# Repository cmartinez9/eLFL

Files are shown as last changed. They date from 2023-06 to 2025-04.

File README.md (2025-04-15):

# eLFL (Electric Little Free Library)

## Description

An electric Little Free Library (eLFL) is a regular Little Free Library retrofitted with a solar PV panel, battery storage, and charging electronics. It is developed by students at UW-Madison in collaboration with the Great Lakes Community Conservation Corps (GLCCC). It serves as a way to provide free community access to clean electricity. 

## Requirements

- Altium Designer 
- Arduino IDE [Used 2.0.4]
- Python

## Installation

* **eLFL Node** 
    
    * Arduino IDE
        * Open eLFL_Node_v1.ino
        * Download [RadioHead.h](http://www.airspayce.com/mikem/arduino/RadioHead/RadioHead-1.122.zip)
        * Go to "Sketch" -> "Include Library" -> "Add .ZIP Library" -> Select downloaded RadioHead library

## Bill of Materials

|Quantity|Part Number|Desription|Supplier Link|Unit Price|Group|
|:----|:----|:----|:----|:----|:----|
|3|ABX00033|ARDUINO NANO EVERY WITH HEADERS| |16|eLFL PCB|
|6|SEN-13679|CURRENT SENSOR BREAKOUT - ACS723| |9.95|eLFL PCB|
|6|PPTC151LFBN-RC|CONN HDR 15POS 0.1 TIN PCB| |0.98|eLFL PCB|
|3|PPTC051LFBN-RC|CONN HDR 5POS 0.1 TIN PCB| |0.47|eLFL PCB|
|6|SR205E105MAR|CAP CER 1UF 50V Z5U RADIAL| |0.85|eLFL PCB|
|3|PPTC061LFBN-RC|CONN HDR 6POS 0.1 TIN PCB| |0.52|eLFL PCB|
|3|TMP36GT9Z|SENSOR ANALOG -40C-125C TO92-3| |2.4|eLFL PCB|
|3|PPPC091LFBN-RC|CONN HDR 9POS 0.1 GOLD PCB| |0.67|eLFL PCB|
|3|SSL-LX5093LGD|LED GREEN DIFFUSED T-1 3/4 T/H| |0.43|eLFL PCB|
|9|3568|FUSE HOLDER BLADE 500V 30A PCB| |1.33|eLFL PCB|
|3|HLMP-3301|LED RED DIFFUSED T-1 3/4 T/H| |0.47|eLFL PCB|
|6|106CKS450MLU|CAP ALUM 10UF 20% 450V RADIAL| |0.97|eLFL PCB|
|18|1729128|TERM BLK 2P SIDE ENT 5.08MM PCB| |1.162|eLFL PCB|
|3|DEV-13955|OPENLOG WITH HEADERS| |17.5|eLFL PCB|
|3|VOLT-01|VOLTAGE SENSOR MODULE| |5.95|eLFL PCB|
|3|S152AH-915S|RF ANT 915MHZ WHIP TILT RP-SMA| |15.41|eLFL PCB|
|9|PPPC031LFBN-RC|CONN HDR 3POS 0.1 GOLD PCB| |0.37|eLFL PCB|

## Usage

Use a 12V battery, Solar Charge Controller, Solar Panel, and Printed Circuit Board.

## Contributing

[Insert instructions for how others can contribute to your project. This could include guidelines for submitting bug reports, suggestions for new features, or instructions for how to contribute code.]

## Credits

[Insert credits for any third-party libraries, resources, or tools that you used in your project.]

## License

[Insert the license that your project is released under. This could be a standard open-source license like the MIT License or a custom license that you created specifically for your project.]

## Contact

Christian Martinez (cmartinez9@wisc.edu)

Maitreyee Marathe (mmarathe@wisc.edu)

Mridhul Baskaran (mbaskaran@wisc.edu)

Joshika Nachiappan (nachiappanra@wisc.edu)

Savannah Ahnen (sahnen@wisc.edu)

Giri Venkataramanan (giri@engr.wisc.edu)

Bhuvana Krishnaswamy (bhuvana@ece.wisc.edu)

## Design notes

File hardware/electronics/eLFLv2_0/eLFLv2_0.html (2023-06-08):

Reporting Options

# File in Newer Format

Date | : | 4/23/2022
Time | : | 3:18:30 PM
Project name | : | C:\Users\Public\Documents\Altium\Projects\elfl\eLFLv2_0\eLFLv2_0.PrjPcb
Schematic documents | : | eLFLv2_0.SchDoc

Version | Warning
21.9.0 | Internal Pull Up/Down resistor in components are not supported in this version.

These files were generated in a later version of Altium Designer. Be aware that some data may have been added through functionality not available in your current version and will therefore not be available to you.

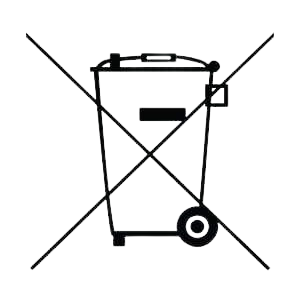
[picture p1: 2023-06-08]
hardware/electronics/eLFL_Particle_Breakout/noTrash-removebg-preview.png

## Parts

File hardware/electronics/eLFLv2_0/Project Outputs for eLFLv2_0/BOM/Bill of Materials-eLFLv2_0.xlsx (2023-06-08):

Comment | Description | Designator | Footprint | LibRef | Quantity
Terminal Connector | Barrier Strip Terminal Block, 13.5A, 1.5mm2, 1 Row(s), 1 Deck(s) | 12V Battery, Door Sensor, Output of Batt Charger, USB1, USB2 | Anderson Power Pole | 1729128 | 5
3568 | Fuses/Accessories | Battery Fuse, USB1 Fuse, USB2 Fuse | Fuse | 3568 | 3
Buck Converter | Buck Converter 5V output | BC1 | Buck Converter | Buck Converter | 1
10uF | Aluminum Electrolytic Capacitor, Polarized, Aluminum (wet), 450V, 20% +Tol, 20% -Tol, 10uF, Through Hole Mount | C1 | Capacitor | 106CKS450MLU | 1
1uF | Capacitor | C2 | RAD-0.3 | Cap | 1
10uF | Ceramic Capacitor, Multilayer, Ceramic, 100V, 10% +Tol, 10% -Tol, X6S, 22% TC, 10uF, Surface Mount, 1206 | C3, C4 | Ceramic Capacitor | C3216X6S2A106K160AC | 2
HLMP-3301 | T-1 3/4 (5 mm) Diffused LED Lamp, 1.9 V, -40 to 100 degC, 2-Pin THD, RoHS, Bulk | Green, Red | AVAG-HLMP-3301-2 | CMP-2000-06411-1 | 2
12uF | General Purpose Inductor, 12uH, 20%, 1 Element, SMD, 1813 | I1 | Inductor | RLS-126-R Inductor | 1
ACS723 | Header, 5-pin | P1, P3 | Current Sensor | Current Sense | 2
OpenLog | Header, 6-Pin | P2 | HDR1X6 | Header 6 | 1
Real Time Clock | Real Time Clock, Volatile, 1 Timer(s), CMOS, PDIP8 | P5 | Real Time Clock | DS1307 | 1
Voltage Sensor | Header, 5-pin | Q | Voltage Sensor | Voltage Sense | 1
Res1 | Resistor | R1, R2, R3, R4 | AXIAL-0.3 | Res1 | 4
Mounting Hole | M2 PTH (2.5mm), 5mm pad | ST1, ST2, ST3, ST4 | PTH-M2D5X5 | CMP-00028-00004-2 | 4
Terminal Connector | Barrier Strip Terminal Block, 13.5A, 1.5mm2, 1 Row(s), 1 Deck(s) | T1, T2, T3, T4, T5 | Terminal Block | 1729128 | 5
TMP36GT9Z | Low Voltage Temperature Sensor, 2.7 to 5.5 V Supply, Industrial, 3-pin TO92 (T-3), Tray | U1 | HDR1X3 | ADI-TMP3X-T-3 | 1
ABX00053 | ARDUINO NANO RP2040 CONNECT WITH | U2 | Arduino Nano Every | ABX00053 | 1
RF95 Module |  | U3 | RF95 | RF95 Module | 1
Lora_Testpoints | This act as testing point for 9 pin header on Lora for ELFL projects | U4 | LORA TESTPOINTS | Lora_Testpoints | 1

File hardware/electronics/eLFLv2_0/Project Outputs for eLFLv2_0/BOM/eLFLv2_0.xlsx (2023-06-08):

Line # | Name | Description | Designator | Revision ID | Revision State | Revision Status | Quantity | Manufacturer 1 | Manufacturer Part Number 1 | Manufacturer Lifecycle 1 | Supplier 1 | Supplier Part Number 1 | Supplier Unit Price 1 | Supplier Subtotal 1
 | Terminal Connector | Barrier Strip Terminal Block, 13.5A, 1.5mm2, 1 Row(s), 1 Deck(s) | 12 V Battery Input, Battery Charge Control Output1, Door Sensor1, Load Output1, USB1, USB2 |  | Not managed |  | 6 | Phoenix Contact | 1729128 | Volume Production | Digi-Key | 277-1247-ND | 1.32 | 7.92
 | Voltage Sensor | Header, 5-pin | 12Voltage Sensor |  | Not managed |  | 1
 | ACS723 | Header, 5-pin | Battery Current Sensor1, Load Current Sensor1 |  | Not managed |  | 2
 | 1uF | Capacitor | C1, C5 |  | Not managed |  | 2
 | 10uF | Aluminum Electrolytic Capacitor, Polarized, Aluminum (wet), 450V, 20% +Tol, 20% -Tol, 10uF, Through Hole Mount | C4, C6 |  | Not managed |  | 2 | CDE Illinois Capacitor | 106CKS450MLU | Volume Production | Digi-Key | 106CKS450MLU-ND
 | 3568 | Fuses/Accessories | F1, F2, F3 |  | Not managed |  | 3 | Keystone Electronics | 3568 | Volume Production | Digi-Key | 36-3568-ND | 1.33 | 3.99
 | HLMP-3301 | T-1 3/4 (5 mm) Diffused LED Lamp, 1.9 V, -40 to 100 degC, 2-Pin THD, RoHS, Bulk | Green1, Red1 | CMP-2000-06411-1 | Released | Up to date | 2 | Broadcom Avago | HLMP-3301 | Volume Production | Newark | 40K0048 | 0.46 | 0.92
 | RF95 Module |  | Lora Module1 |  | Not managed |  | 1
 | Lora_Testpoints | This act as testing point for 9 pin header on Lora for ELFL projects | Lora Test Points1 |  | Not managed |  | 1
 | Open Log |  | OpenLog |  | Not managed |  | 1
 | Res1 | Resistor | R1, R2, R3, R4 |  | Not managed |  | 4
 | RTC Breakout Board |  | RTC |  | Not managed |  | 1
 | Mounting Hole | M2 PTH (2.5mm), 5mm pad | ST1, ST2, ST3, ST4 |  | Unknown server |  | 4
 | TMP36GT9Z | Low Voltage Temperature Sensor, 2.7 to 5.5 V Supply, Industrial, 3-pin TO92 (T-3), Tray | Temperature Sensor1 |  | Not managed |  | 1
 | ABX00053 | ARDUINO NANO RP2040 CONNECT WITH | U1 |  | Not managed |  | 1

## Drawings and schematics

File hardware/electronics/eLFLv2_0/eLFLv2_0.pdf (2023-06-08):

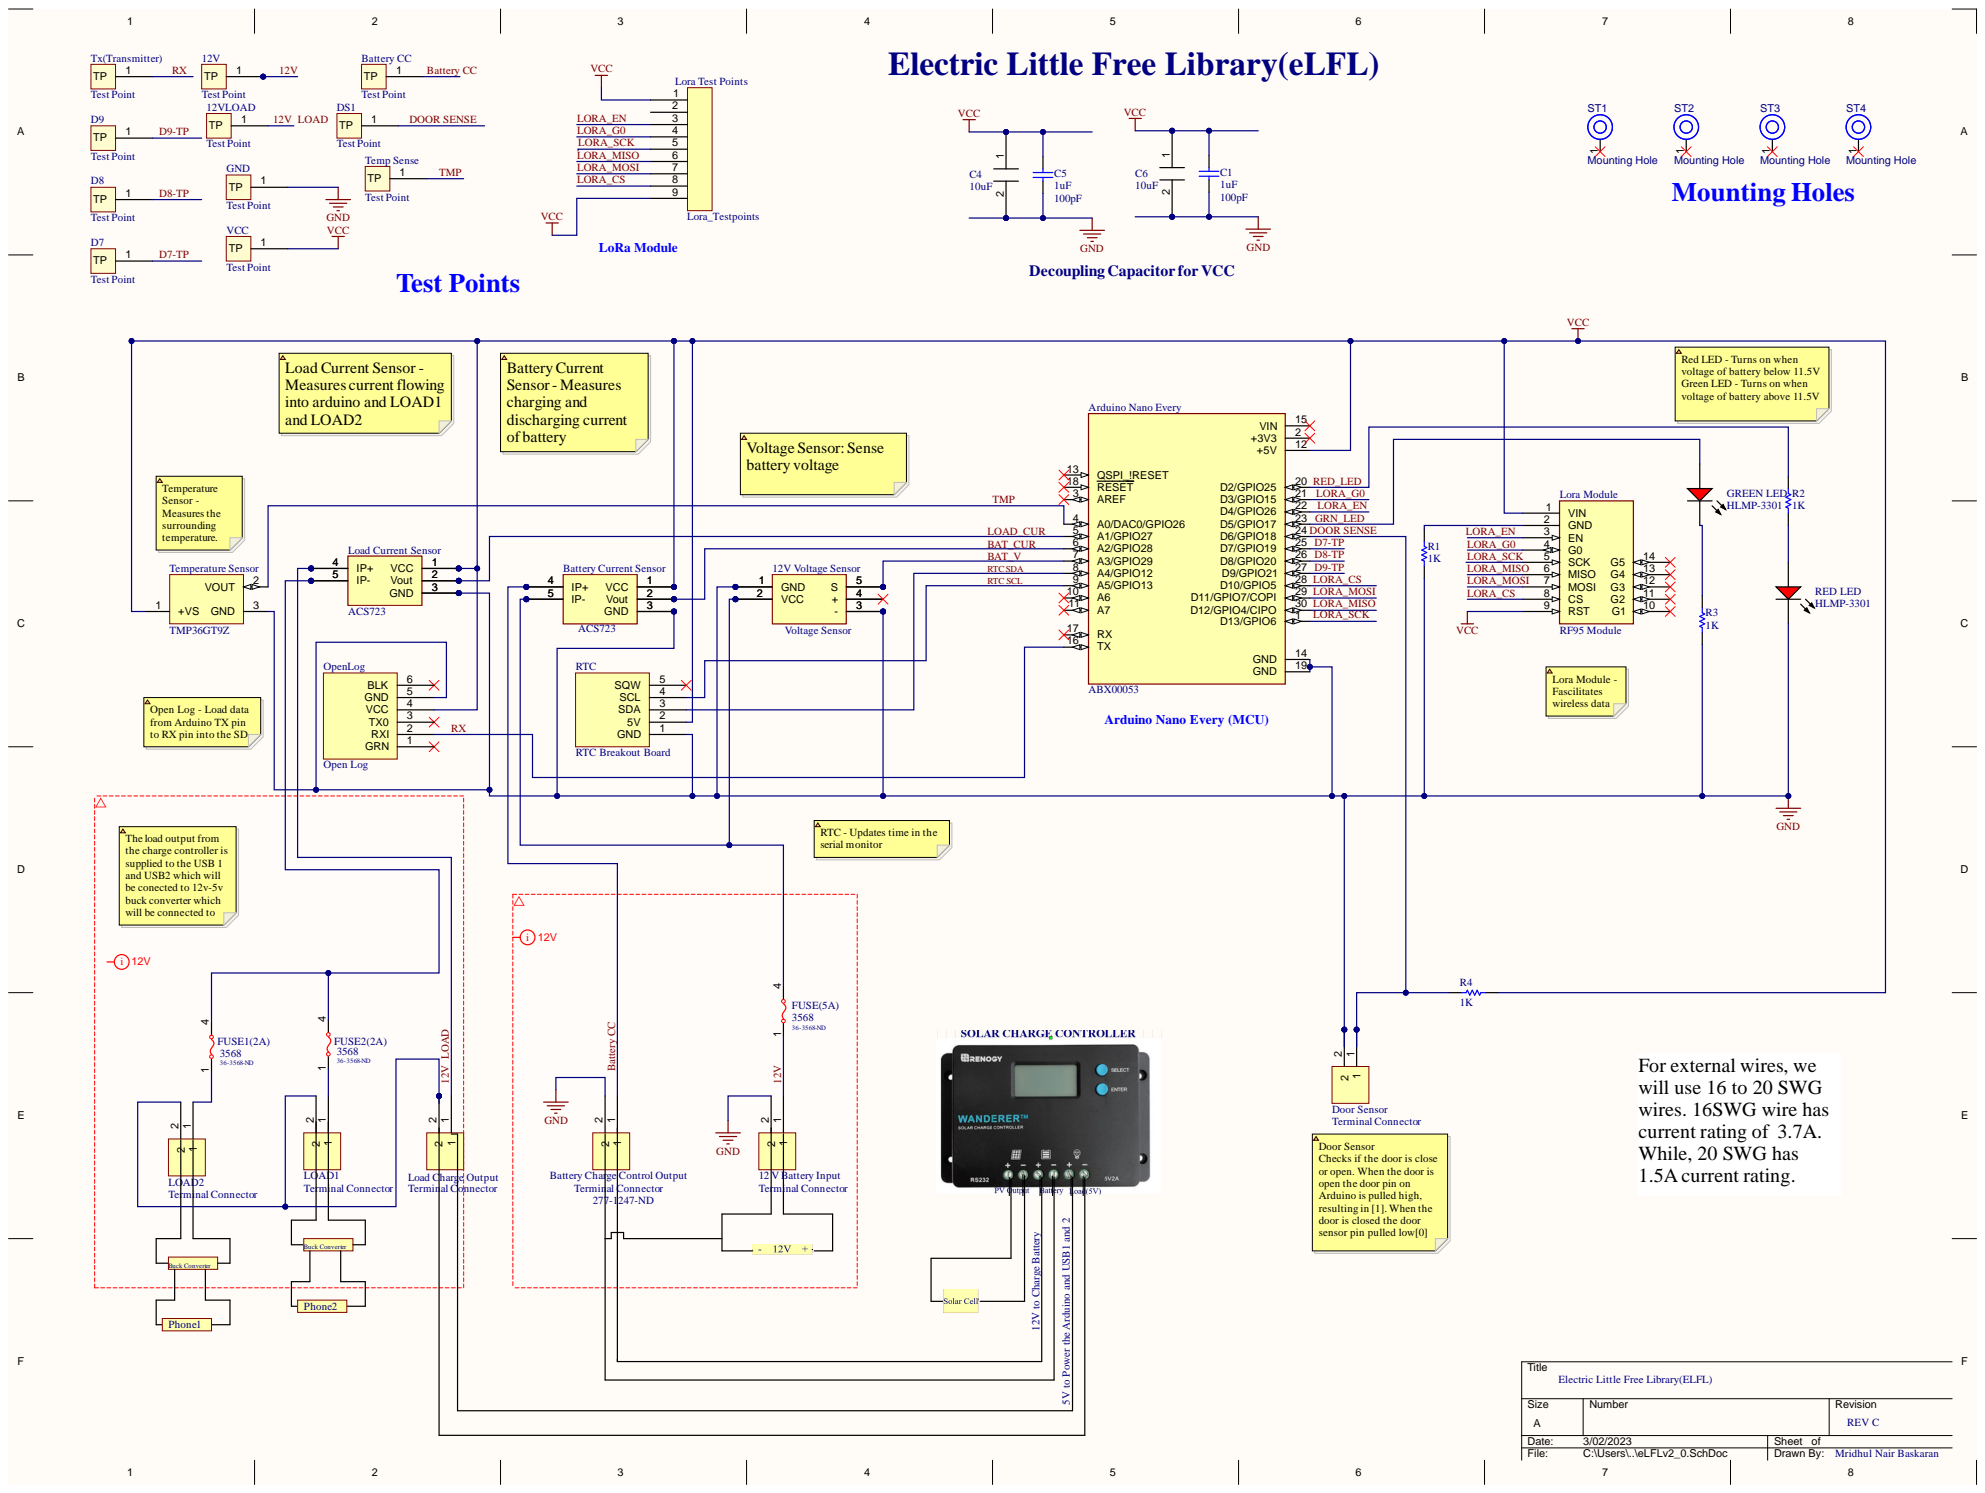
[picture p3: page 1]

Electric Little Free Library(eLFL)

Decoupling Capacitor for VCC

Red LED - Turns on when
voltage of battery below 11.5V
Green LED - Turns on when
voltage of battery above 11.5V

A1/GPIO27 5 | DOOR SENSE | LORA_EN | EN 3

OpenLog

Open Log - Load data
from Arduino TX pin
to RX pin into the SD

Arduino Nano Every (MCU)

RTC - Updates time in the
serial monitor

The load output from
the charge controller is
supplied to the USB 1
and USB2 which will
be conected to 12v-5v
buck converter which
will be connected to

For external wires, we
will use 16 to 20 SWG
wires. 16SWG wire has
current rating of 3.7A.
While, 20 SWG has
1.5A current rating.

Door Sensor
Checks if the door is close
or open. When the door is
open the door pin on
Arduino is pulled high,
resulting in [1]. When the
door is closed the door
sensor pin pulled low[0]

Load Charge Output Terminal Connector

Battery Charge Control Output
Terminal Connector

5V to Power the Arduino and USB1 and 2

Electric Little Free Library(ELFL)

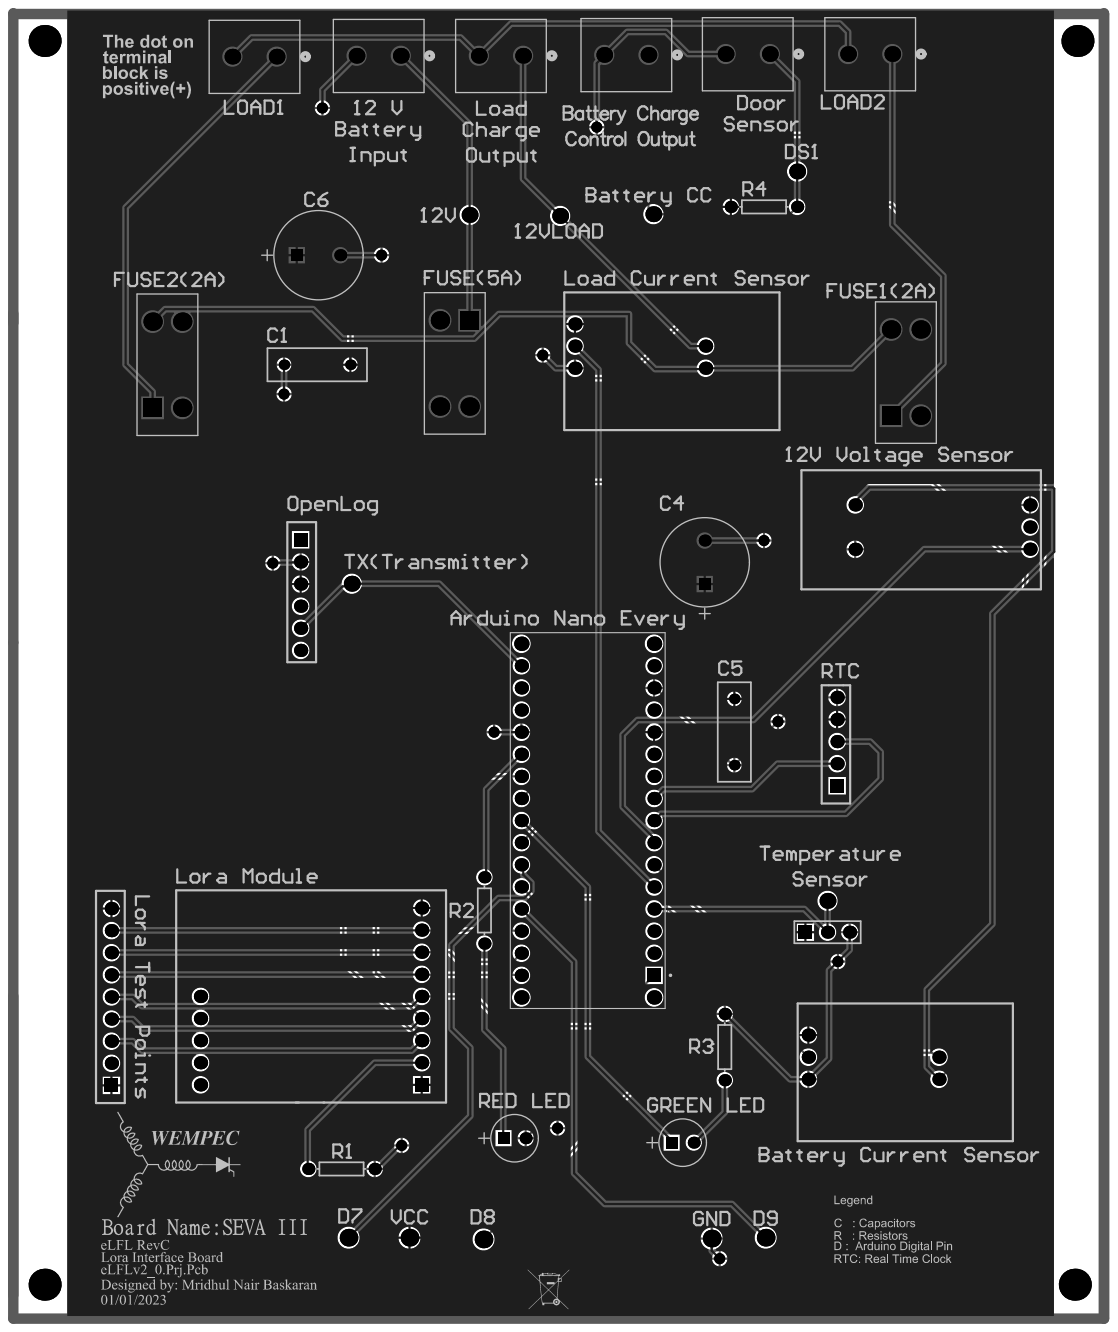
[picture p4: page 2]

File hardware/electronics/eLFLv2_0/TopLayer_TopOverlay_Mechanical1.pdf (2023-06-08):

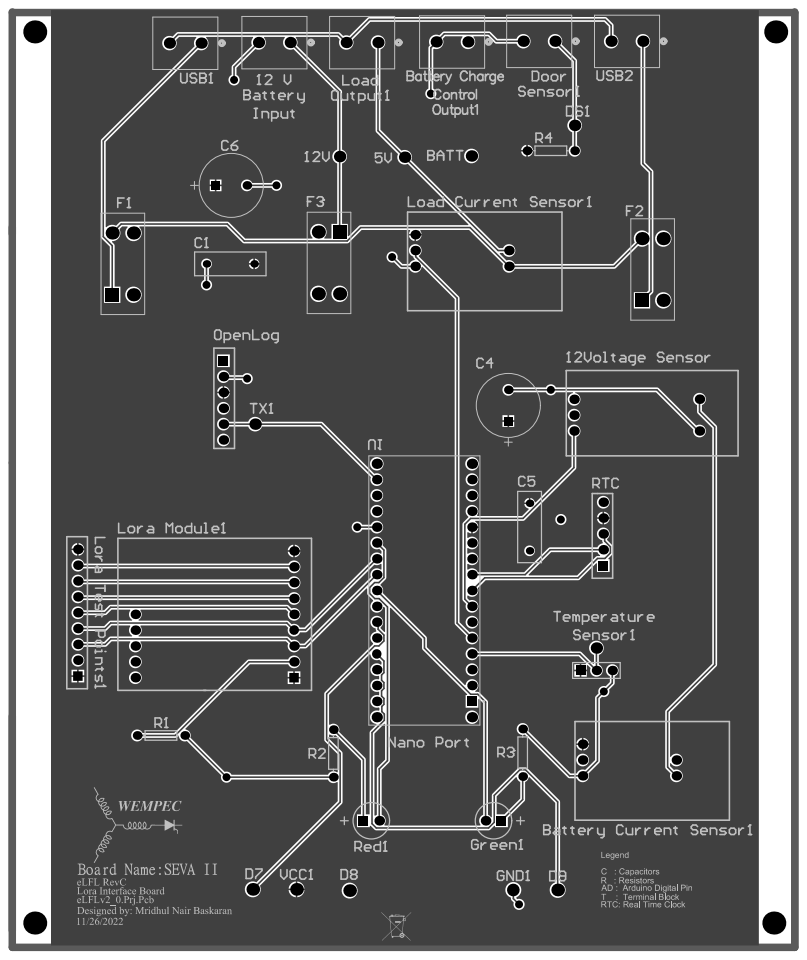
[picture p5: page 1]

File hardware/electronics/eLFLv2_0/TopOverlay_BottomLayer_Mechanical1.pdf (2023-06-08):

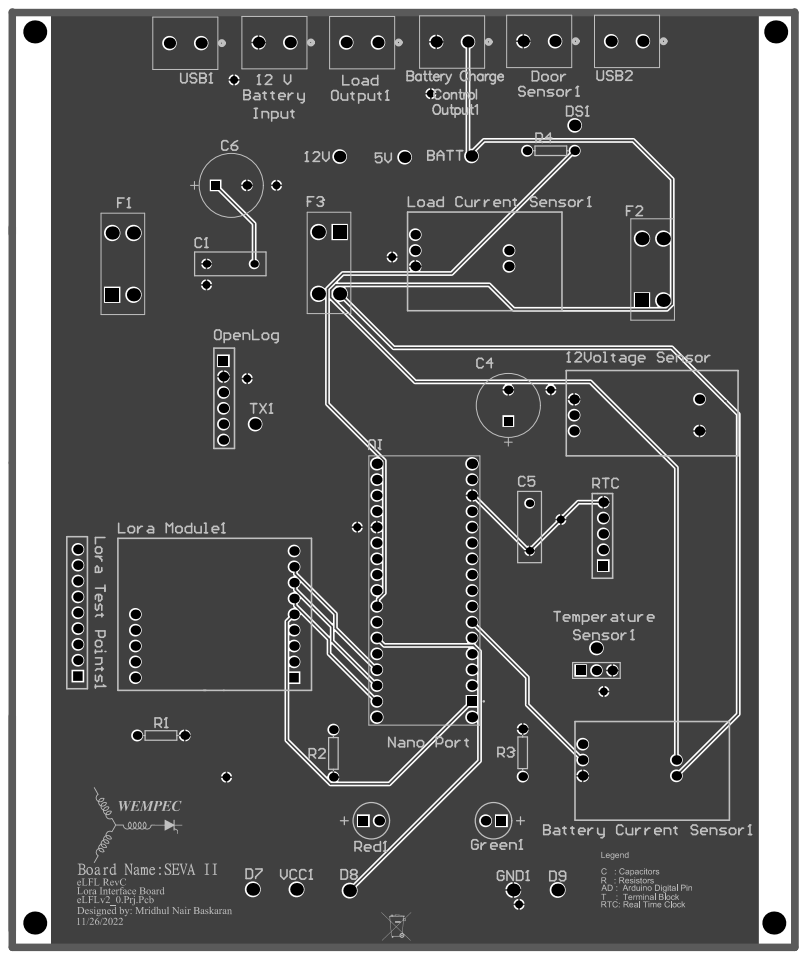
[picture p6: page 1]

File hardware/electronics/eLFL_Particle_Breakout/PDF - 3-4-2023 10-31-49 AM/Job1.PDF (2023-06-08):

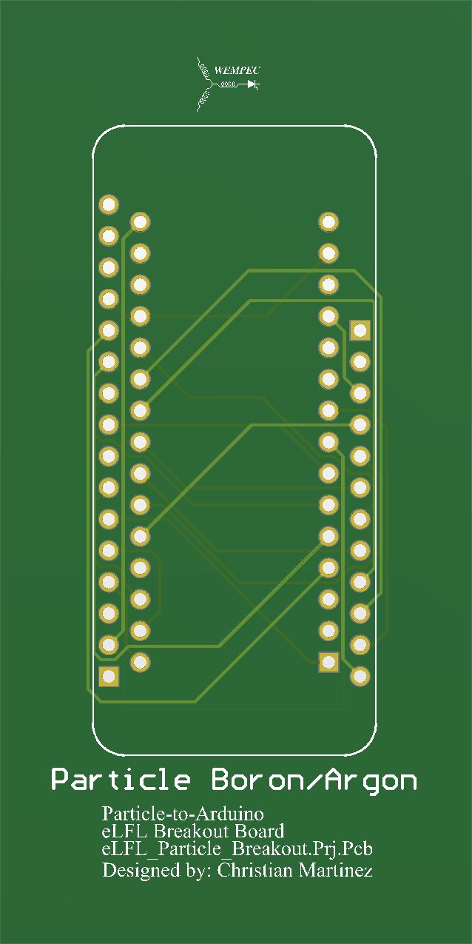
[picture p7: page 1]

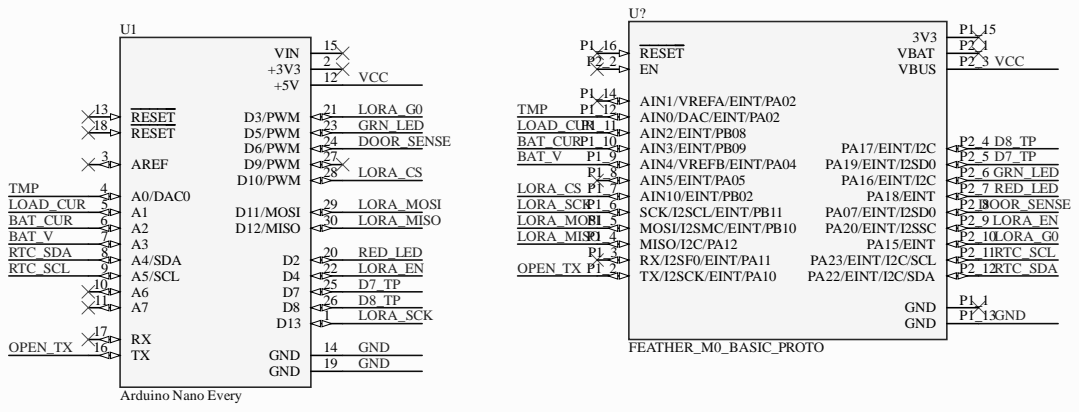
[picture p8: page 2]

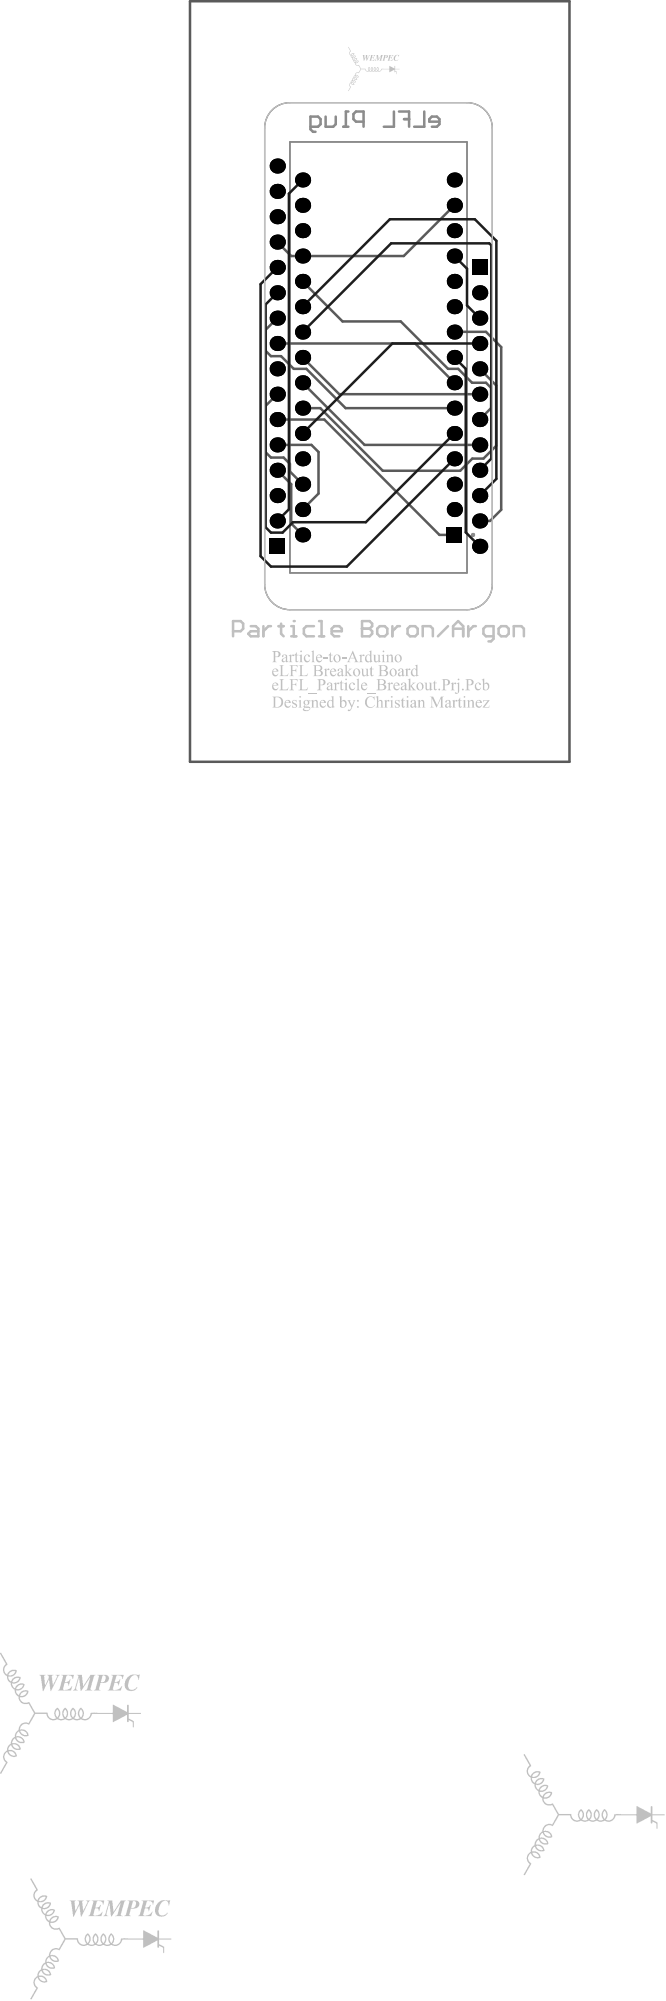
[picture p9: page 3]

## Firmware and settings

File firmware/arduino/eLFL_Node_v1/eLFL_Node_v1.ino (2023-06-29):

#include <ArduinoJson.h>
#include <ArduinoJson.hpp>


/* electric Little Free Library - v0
  Author: Maitreyee Marathe
  Last modified: Apr 1, 2022
  Platform: Arduino Nano Every
  This program is used to record sensor readings from a monitoring system for 
  a solar+battery powered USB charging station and log it to an SD card (OpenLog)
  connected via the TX pin.
  The Arduino Nano Every has two serial ports:
  "Serial" - for computer via micro-USB port
  "Serial1" - for the TX/RX pins (pins 16/17)

  Sensor Inputs
  - Load Current
  - Battery Current (+ve when getting charged)
  - Temperature
  - Battery Voltage

  Outputs
  - Green LED ON, Red LED OFF- voltage above v_high
  - Green LED OFF, Red LED ON - voltage below v_low
  - Previous state - voltage between v_low and v_high (deadband)
*/

// Date and time functions using a DS1307 RTC connected via I2C and Wire lib
//#include <LowPower.h>
//#include <RadioHead.h>
//#include <RH_RF95.h>
#include "RTClib.h"
// #include <ArduinoJson.h>
// #include <ArduinoJson.hpp>

RTC_DS1307 rtc;

#define NODE_ID 23

#define TEMP_SENSE
#define LOAD_SENSE
#define CUR_SENSE
#define V_SENSE
//#define DOOR_SENSE
//#define LORA_ACTIVE
//#define OPEN_LOG_ACTIVE
#define RTC_ACTIVE

#define MODEM_CONFIG 21

// +2 to +20, 13 default
// #define TX_POWER 23
// #define SF       10
// #define BW       125000
// #define CR       7
#define TX_POWER 23
#define SF 11
#define BW 500000
#define CR 5
#define EN 4

#ifdef LORA_ACTIVE
RH_RF95 rf95(10, 3);
#endif

#define TEMP_PIN A0
#define LOAD_PIN A1
#define CUR_BATT_PIN A2
#define V_BATT_PIN A3
#define DOOR_PIN A6
#define RED_LED_PIN 2
#define GRN_LED_PIN 5

// Sensor parameters
int iLoad_value = 0;
int iBatt_value = 0;
int temperature_value = 0;
int vBatt_value = 0;
int door_value = 0;
// delay time for every 10 minutes
unsigned long minute = 10;
unsigned long readDelay = minute * 60000;

float vBatt = 0;
const float sensitivity = 2.5;  // current sensor sensitivity
const float Vref_Load = 2500;   // load current sensor output voltage with no current
const float Vref_Batt = 2420;   // battery current sensor output voltage with no current
const float v_low = 11.5;       // battery voltage limit to switch ON red LED
const float v_high = 12;        // battery voltage limit to swithc ON green LED
const float logTime = 10000;    // time duration (ms) between two data entries to the SD card
const int delayTime = 2;        // time duration (ms) between two sensor readings
const int avgSamples = 10;      // no. of sensor readings to compute average

StaticJsonDocument<200> doc;

DateTime now;

void setup() {

  Serial.begin(9600);
  Serial.println("Start Init");
  initSensors();
#ifdef LORA_ACTIVE
  initLoRa();
#endif
  Serial.println("Finished Init");
}


void loop() {
  doc["node"] = NODE_ID;

#ifdef RTC_ACTIVE
  checkTime();
#endif

  sampleAnalog();

  calcValues();

#ifdef DOOR_SENSE
  checkDoor();
#endif

  chngLedStatus();

  // delay(logTime - delayTime*avgSamples);

  serializeJsonPretty(doc, Serial);
  Serial.println();
#ifdef LORA_ACTIVE
  sendPacket();
#endif
  doc.clear();
  delay(readDelay);
  // delay(logTime - delayTime*avgSamples);
  //LowPower.powerDown(SLEEP_8S, ADC_OFF, BOD_OFF);
}

bool initSensors() {
#ifdef TEMP_SENSE
  pinMode(TEMP_PIN, INPUT);
#endif
#ifdef LOAD_SENSE
  pinMode(LOAD_PIN, INPUT);
#endif
#ifdef CUR_SENSE
  pinMode(CUR_BATT_PIN, INPUT);
#endif
#ifdef V_SENSE
  pinMode(V_BATT_PIN, INPUT);
#endif
#ifdef DOOR_SENSE
  pinMode(DOOR_PIN, INPUT);
#endif
  pinMode(RED_LED_PIN, OUTPUT);
  pinMode(GRN_LED_PIN, OUTPUT);

#ifdef RTC_ACTIVE
  if (!rtc.begin()) {
    Serial.println("Couldn't find RTC");
    Serial.flush();
    while (1) delay(10);
  }


  if (!rtc.isrunning()) {
    Serial.println("RTC is NOT running, let's set the time!");
    // When time needs to be set on a new device, or after a power loss, the
    // following line sets the RTC to the date & time this sketch was compiled
    rtc.adjust(DateTime(F(__DATE__), F(__TIME__)));
  }
 
#endif
}

void checkTime() {
  now = rtc.now();
  String month = String(now.month(), DEC);
  String day = String(now.day(), DEC);
  String year = String(now.year(), DEC);
  String hour = String(now.hour(), DEC);
  String min = String(now.minute(), DEC);
  String sec = String(now.second(), DEC);
  String date = month + "-" + day + "-" + year;
  String time = hour + ":" + min + ":" + sec;
  doc["date"] = date;
  doc["time"] = time;
  Serial.println("TIME CHECKED");
}

bool sampleAnalog() {
  // Collect samples every (delayTime) ms and compute average
  iLoad_value = 0;
  iBatt_value = 0;
  temperature_value = 0;
  vBatt_value = 0;

  for (int i = 0; i < avgSamples; i++) {
#ifdef LOAD_SENSE
    iLoad_value += analogRead(LOAD_PIN);
    if (i == avgSamples - 1)
      Serial.println("LOAD CHECKED");
#endif
#ifdef CUR_SENSE
    iBatt_value += analogRead(CUR_BATT_PIN);
    if (i == avgSamples - 1)
      Serial.println("CURRENT CHECKED");
#endif
#ifdef TEMP_SENSE
    temperature_value += analogRead(TEMP_PIN);
    if (i == avgSamples - 1)
      Serial.println("TEMP CHECKED");
#endif
#ifdef V_SENSE
    vBatt_value += analogRead(V_BATT_PIN);
    if (i == avgSamples - 1)
      Serial.println("VOLT CHECKED");
#endif
    delay(delayTime);
  }
}

bool calcValues() {

// Load Current (mA)
#ifdef LOAD_SENSE
  iLoad_value = iLoad_value / avgSamples;
  float voltage_temp = 4.88 * (iLoad_value);
  float iLoad = -(voltage_temp - Vref_Load) * sensitivity;  // negative due to wiring
  doc["load_cur"] = iLoad;
  Serial.println("LOAD CALCULATED");
#endif

// Battery Current (mA)
#ifdef CUR_SENSE
  iBatt_value = iBatt_value / avgSamples;
  float voltage_temp2 = 4.88 * (iBatt_value);
  float iBatt = (voltage_temp2 - Vref_Batt) * sensitivity;

  doc["bat_cur"] = iBatt;
  Serial.println("CURRENT CALCULATED");
#endif

// Battery Voltage (V)
#ifdef V_SENSE
  vBatt_value = vBatt_value / avgSamples;
  vBatt = 25 * vBatt_value;
  vBatt = vBatt / 1023;

  doc["bat_volt"] = vBatt;
  Serial.println("VOLT CALCULATED");
#endif

// Temperature (Celsius)
#ifdef TEMP_SENSE
  temperature_value = temperature_value / avgSamples;
  float voltage_temp3 = temperature_value * 5.0;
  voltage_temp3 /= 1024.0;
  //converting from 10 mv per degree with 500 mV offset to degrees
  float temperature = (voltage_temp3 - 0.5) * 100;

  doc["temp"] = temperature;
  Serial.println("TEMP CALCULATED");
#endif
}

bool checkDoor() {
  // Door sensor
  door_value = digitalRead(DOOR_PIN);  //= 0 if door closed, = 1 if door open

  doc["door"] = door_value;
  Serial.println("DOOR CHECKED");
}

bool chngLedStatus() {
  // Green LED ON when battery voltage more than v_high
  // Red LED ON when battery voltage less than v_low
  // Previous state when battery voltage between v_low and v_high (deadband)
  if (vBatt >= v_high) {
    digitalWrite(GRN_LED_PIN, HIGH);
    digitalWrite(RED_LED_PIN, LOW);
    Serial.println("LED CHANGED GREEN");
  } else if (vBatt <= v_low) {
    digitalWrite(GRN_LED_PIN, LOW);
    digitalWrite(RED_LED_PIN, HIGH);
    Serial.println("LED CHANGED RED");
  } else {
    Serial.println("NO LED CHANGE");
  }
}
#ifdef LORA_ACTIVE
bool initLoRa() {
  // pinMode(EN, OUTPUT);
  // digitalWrite(EN, HIGH);

  while (!Serial)
    ;  // Wait for serial port to be available
  if (!rf95.init())
    Serial.println("LORA INIT FAILED");

  rf95.waitPacketSent();
  // Defaults after init are 434.0MHz, 13dBm, Bw = 125 kHz, Cr = 4/5, Sf = 128chips/symbol, CRC on

  rf95.setModemConfig(MODEM_CONFIG);  // set new modem configuration
  rf95.setFrequency(915.0);
  rf95.setTxPower(TX_POWER, false);  // set new transmit power configuration
  rf95.setSpreadingFactor(SF);       // set new spreading factor 2^10
  rf95.setSignalBandwidth(BW);       // set new bandwidth
  rf95.setCodingRate4(CR);           // set new coding rate
  rf95.setPayloadCRC(true);
}

bool sendPacket() {
  char packet[200];
  serializeJson(doc, packet);

  bool sent = rf95.send(packet, sizeof(packet));  // Added bool sent in front to check status - true if correctly queues for transmit

  rf95.waitPacketSent();
  Serial.println("PACKET SENT");

  uint8_t buf[RH_RF95_MAX_MESSAGE_LEN];
  uint8_t len = sizeof(buf);

  if (rf95.waitAvailableTimeout(2000)) {
    if (rf95.recv(buf, &len)) {
      Serial.print("RECIEVED: ");
      Serial.println((char*)buf);
      Serial.print("RSSI: ");
      Serial.println(rf95.lastRssi(), DEC);
    } else {
      Serial.println("RECIEVED FAILED");
    }
    delay(1000);
  } else {
    Serial.println("");
  }
}
#endif

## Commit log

2023-06-08 added pcbs
    [Bill of Materials-eLFLv2_0.xlsx, MY_TP.PCBLIB, Nano_Particle_Breakout.PcbDoc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]
2023-06-08 added prototype 1
2023-06-20 added arduino file
2023-06-29 removed the print statements
2025-04-15 Create PCB V3
2025-04-15 Create PCB Schematics
